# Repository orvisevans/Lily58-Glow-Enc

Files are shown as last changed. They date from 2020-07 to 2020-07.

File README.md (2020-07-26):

# Lily58 × qtkb Glow + Rotary Encoders

This is still very much under active development. I've ordered the pcb and parts and am waiting for them to arrive. Since then, I've found some incompatibilities between the design and product list. I've not yet tested in the real world or worked out there bugs.

Lily58 is 6×4+4keys column-staggered split keyboard.
This fork adds an encoder to the key below the controller.

I got this board manufactured by JLCPCB. Just upload the file called gerber.zip to their quote tool, choose how many (5 is minimum), choose your color, (default options are fine) and order! Mine were $8.40 for a set of 5 and $9.03 shipping in July 2020.

This picture is from the original Lily58 Glow. Pictures of this project are forthcoming.
Lily in the nighttime

## PCB Front

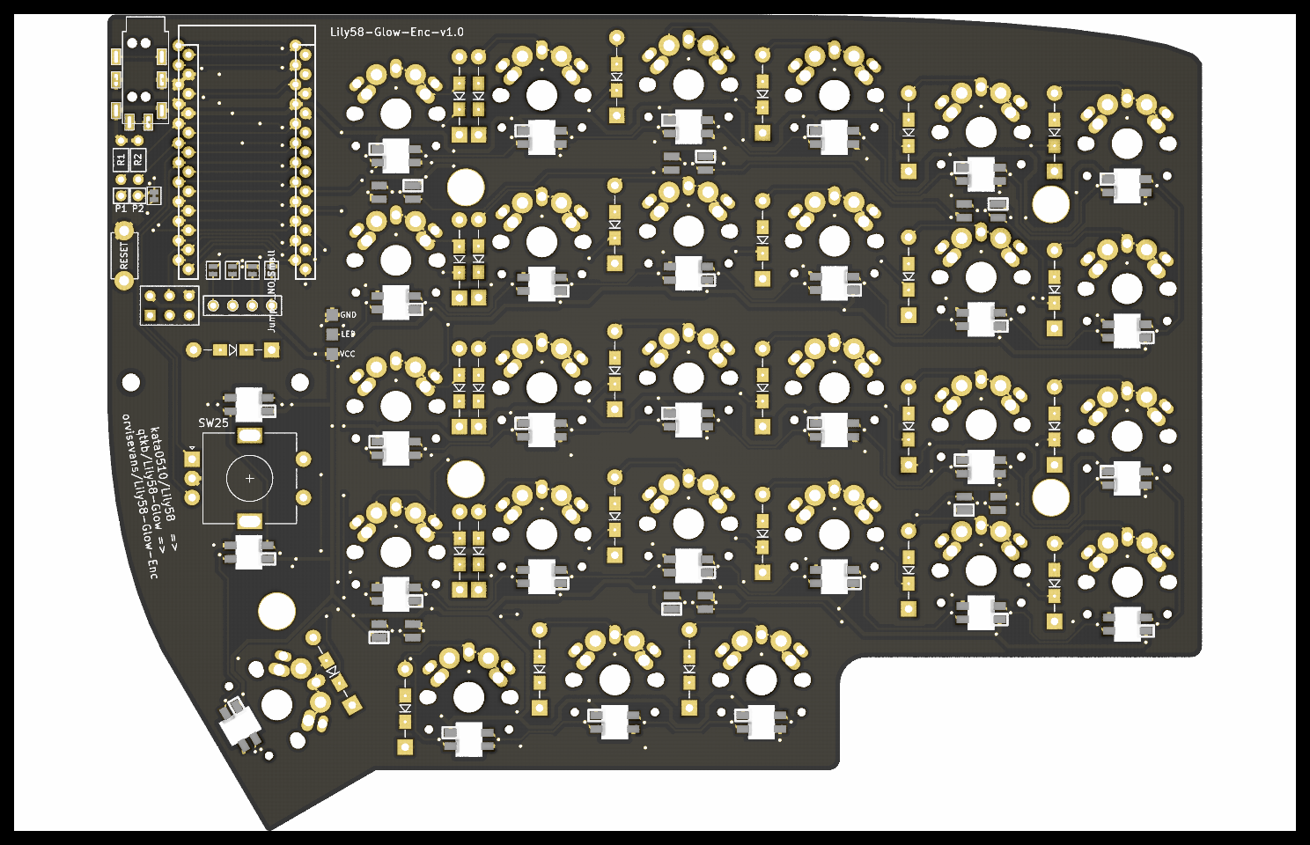
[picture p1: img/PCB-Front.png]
PCB Front


## PCB Back

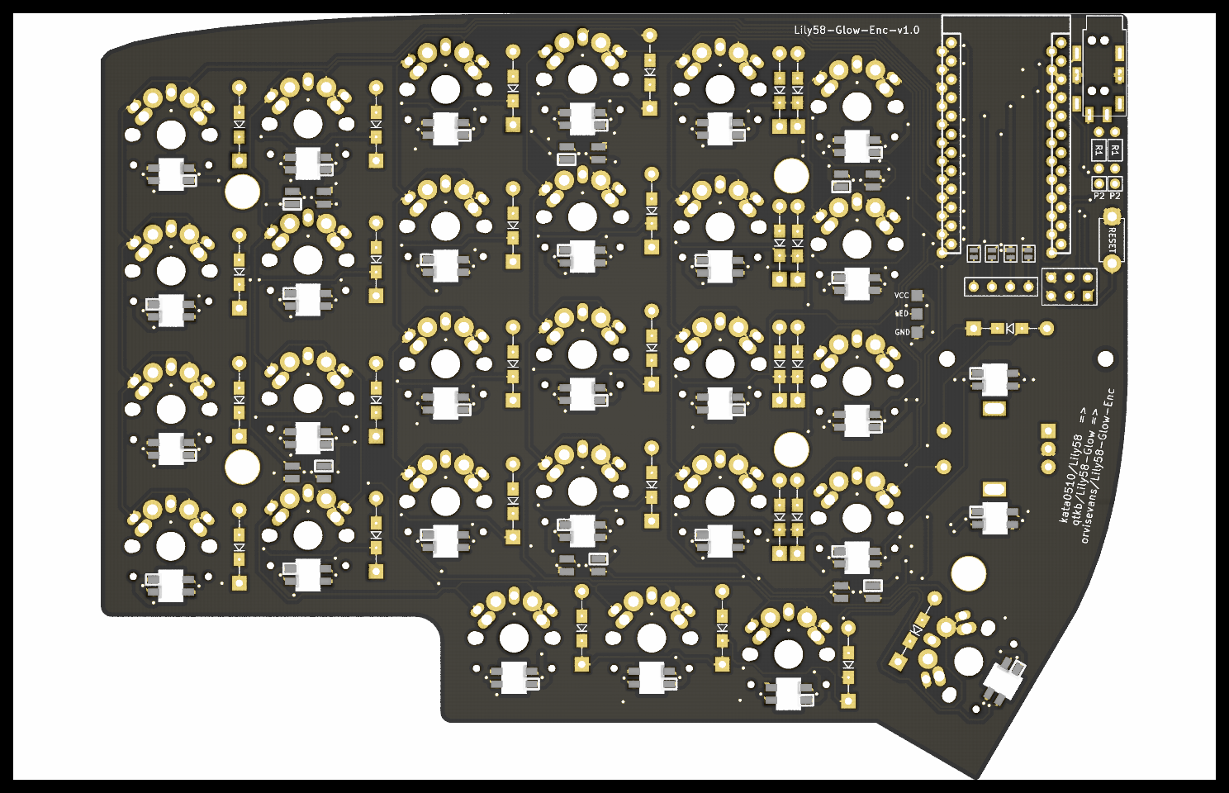
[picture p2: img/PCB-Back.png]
PCB Back


# Parts

| Part Name | Quantity | Link | Price/Unit | Total |
| --- | --- | --- | --- | --- |
| Lily58L PCB | 2 | JLCPCB | \$8.72 | \$17.43  |
| Lily58L Case | 1 | Using 2 more circuit boards as the bottom. No other case for now. | \$0.00 | \$0.00 |
| Pro Micro | 2 | https://www.aliexpress.com/item/32888212119.html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,searchweb201602_,searchweb201603_ | \$5.59 | \$11.17  |
| Micro USB Cable | 2 | -- | \$0.00 | \$0.00 |
| OLED module | 2 | https://www.aliexpress.com/item/32861875681.html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,searchweb201602_,searchweb201603_ | \$1.96 | \$3.92 |
| Rotary Encoder | 2 | https://www.aliexpress.com/item/32322425597.html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,searchweb201602_,searchweb201603_ | \$1.68 | \$3.35 |
| Knob | 2 | -- | | \$0.00 |
| Key switch (MX) | 58 | https://www.aliexpress.com/item/32973993662.html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,searchweb201602_,searchweb201603_ | \$0.29 | \$16.99  |
| Kailh switch socket | 58 | https://www.aliexpress.com/item/10000252734106.html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,searchweb201602_,searchweb201603_ | \$0.22 | \$12.90  |
| SK6812 Mini-E LEDs | 60 | https://www.aliexpress.com/item/4000475685852.html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,searchweb201602_,searchweb201603_ | \$0.18 | \$10.71  |
| SK6812 Mini LEDs | 12 | Use the above and snip the feet if necessary | | \$0.00 |
| Diodes 1N4148 (Through-hole) | 58 | https://www.aliexpress.com/item/1934432186.html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,searchweb201602_,searchweb201603_ | \$0.04 | \$2.48 |
| TRRS Jack | 2 | https://www.aliexpress.com/item/33029465106.html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,searchweb201602_,searchweb201603_ | \$1.63 | \$3.26 |
| TRRS Cable | 1 | https://www.aliexpress.com/item/33000197351.html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,searchweb201602_,searchweb201603_ | \$1.79 | \$1.79 |
| Tactile switch | 0 | Needed but not sourced. | | \$0.00 |
| Key Caps | 58 | https://www.aliexpress.com/item/32744591039.html?spm=a2g0o.cart.0.0.1fff3c00zqG7Sv&mp=1 | \$0.44 | \$25.5 |
| M2 Standoffs | 14 | https://www.aliexpress.com/item/32839434178.html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,searchweb201602_,searchweb201603_ | \$0.57 | \$7.99 |
| M2 Screws | 28 | https://www.aliexpress.com/item/32730208891.html?spm=2114.12010612.8148356.21.445e15ccXDyc9g | \$0.21 | \$5.74 |
| | | | Total: | \$115.80 |

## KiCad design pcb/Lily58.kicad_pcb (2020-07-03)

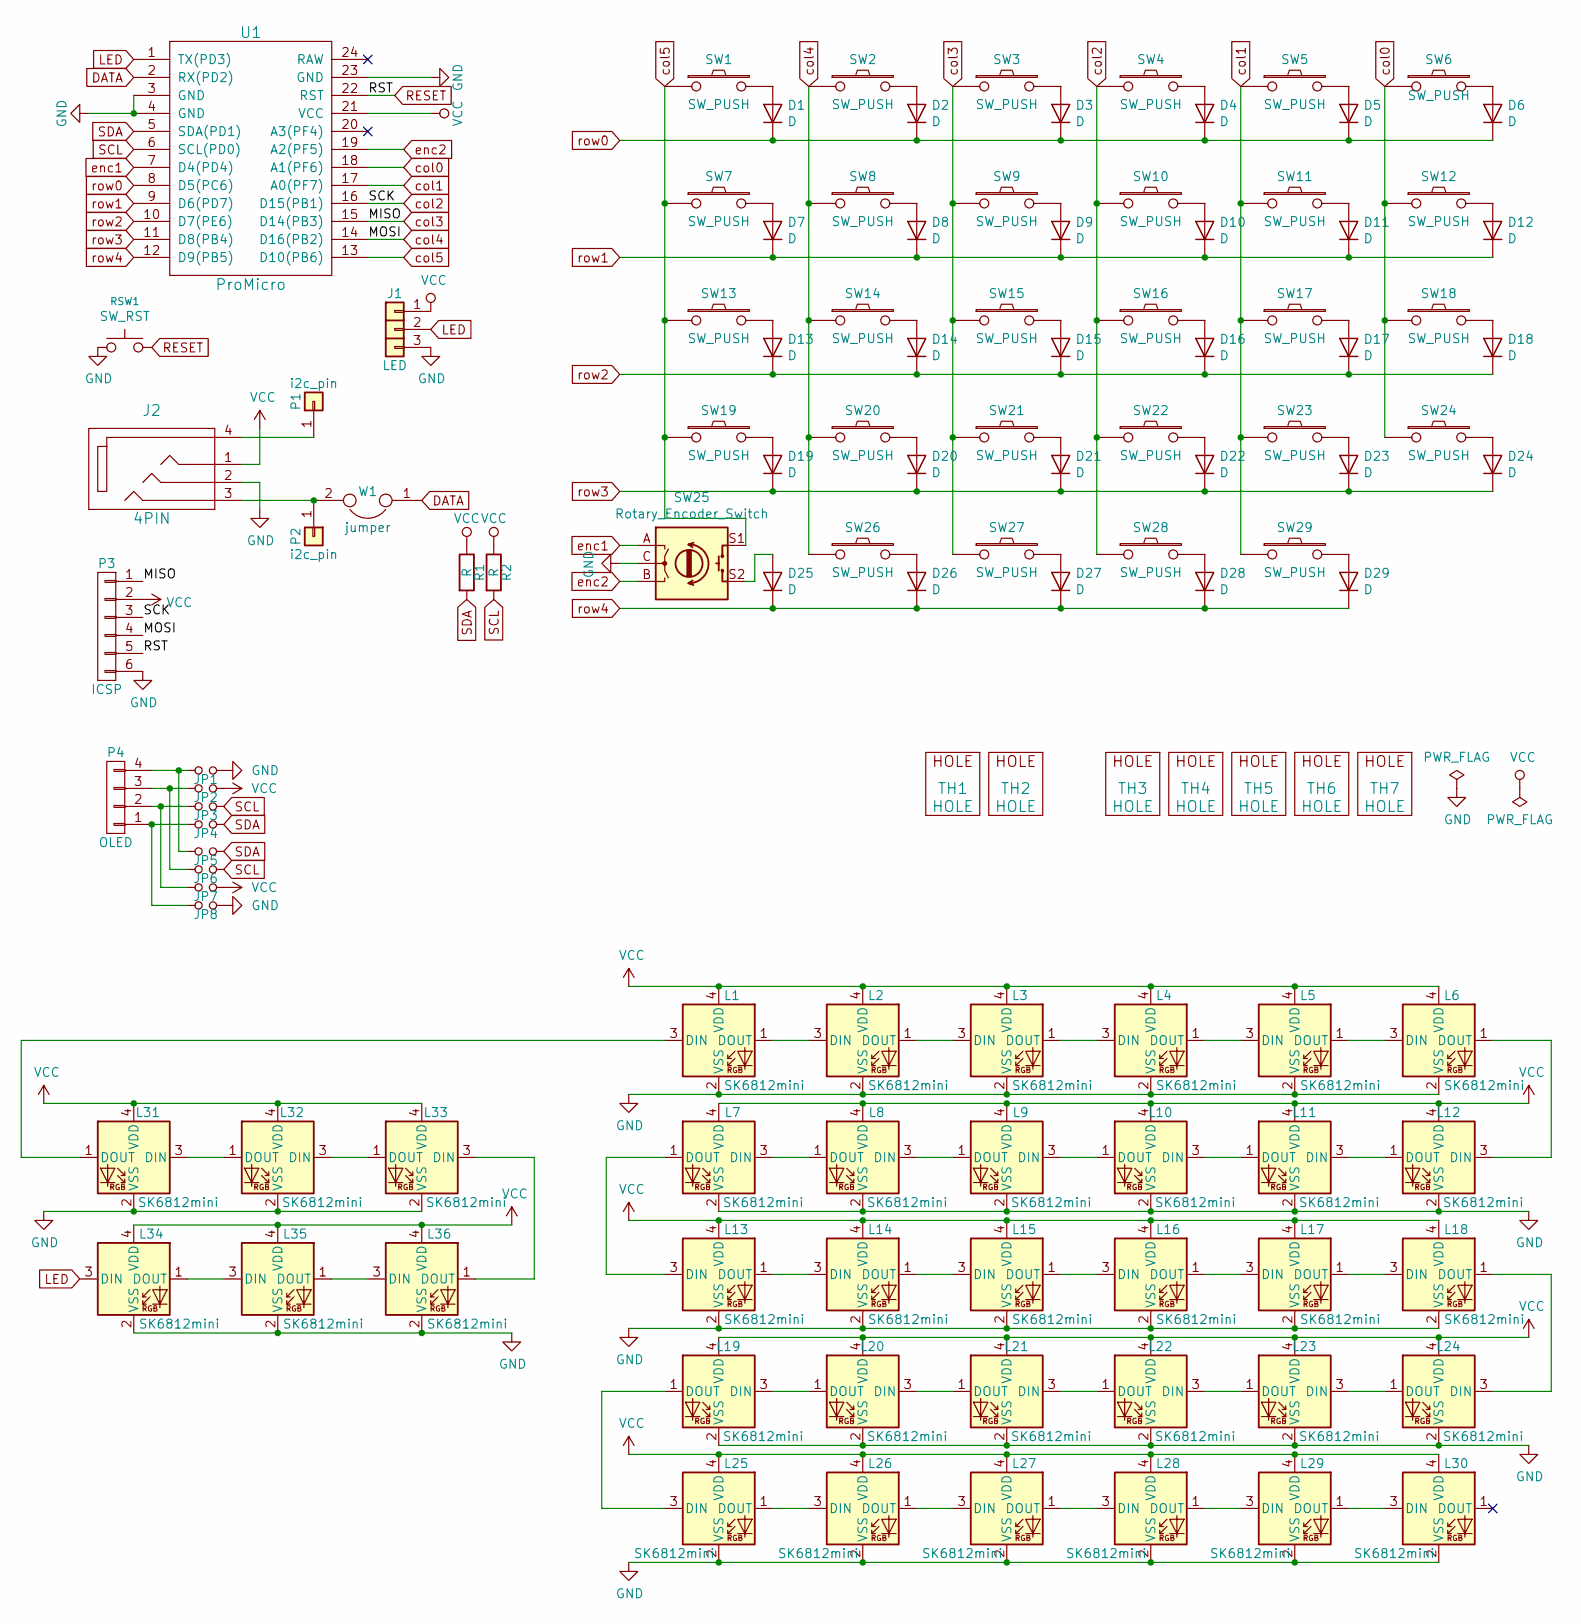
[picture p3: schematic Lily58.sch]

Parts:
D1, D2, D3, D4, D5, D6, D7, D8, D9, D10, D11, D12, D13, D14, D15, D16, D17, D18, D19, D20, D21, D22, D23, D24, D25, D26, D27, D28, D29: D; Diode_TH_SOD123
J1: LED; StripLED
J2: 4PIN; MJ-4PP-9
JP1, JP2, JP3, JP4, JP5, JP6, JP7, JP8: Jumper_NO_Small; Jumper
L1, L2, L3, L4, L5, L6, L7, L8, L9, L10, L11, L12, L13, L14, L15, L16, L17, L18, L19, L20, L21, L22, L23, L24, L25, L26, L27, L28, L29, L30: SK6812mini; SK6812MINI_rev
L31, L32, L33, L34, L35, L36: SK6812mini; SK6812MINI_underglow_rev
P1, P2: i2c_pin; 1pin_conn
P3: ICSP
P4: OLED; MY_SIL-4
R1, R2: R; RESISTOR_mini
RSW1: SW_RST; TACT_SWITCH_TVBP06
SW1, SW2, SW3, SW4, SW5, SW6, SW7, SW8, SW9, SW10, SW11, SW12, SW13, SW14, SW15, SW16, SW17, SW18, SW19, SW20, SW21, SW22, SW23, SW24, SW27, SW28, SW29: SW_PUSH; MX_PG1350_FLIP_HOLES_18mm
SW25: Rotary_Encoder_Switch; RotaryEncoder_Alps_EC11E-Switch_Vertical_H20mm
SW26: SW_PUSH; MX_PG1350_FLIP_HOLES_27mm
TH1, TH2: HOLE; HOLE_M2
TH3, TH4, TH5, TH6, TH7: HOLE; HOLE_M2_TH
U1: ProMicro; ProMicro_rev2
W1: jumper; jumper_data

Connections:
DATA: U1.2 (RX(PD2)), W1.1
GND: J1.3, J2.2, JP1.2, JP8.2, L1.2 (VSS), L2.2 (VSS), L3.2 (VSS), L4.2 (VSS), L5.2 (VSS), L6.2 (VSS), L7.2 (VSS), L8.2 (VSS), L9.2 (VSS), L10.2 (VSS), L11.2 (VSS), L12.2 (VSS), L13.2 (VSS), L14.2 (VSS), L15.2 (VSS), L16.2 (VSS), L17.2 (VSS), L18.2 (VSS), L19.2 (VSS), L20.2 (VSS), L21.2 (VSS), L22.2 (VSS), L23.2 (VSS), L24.2 (VSS), L25.2 (VSS), L26.2 (VSS), L27.2 (VSS), L28.2 (VSS), L29.2 (VSS), L30.2 (VSS), L31.2 (VSS), L32.2 (VSS), L33.2 (VSS), L34.2 (VSS), L35.2 (VSS), L36.2 (VSS), P3.6, RSW1.1, SW25.C, U1.3 (GND), U1.4 (GND), U1.23 (GND)
LED: J1.2, L34.3 (DIN), U1.1 (TX(PD3))
unnamed: D1.2 (A), SW1.2
unnamed: D2.2 (A), SW2.2
unnamed: D3.2 (A), SW3.2
unnamed: D4.2 (A), SW4.2
unnamed: D5.2 (A), SW5.2
unnamed: D6.2 (A), SW6.2
unnamed: D7.2 (A), SW7.2
unnamed: D8.2 (A), SW8.2
unnamed: D9.2 (A), SW9.2
unnamed: D10.2 (A), SW10.2
unnamed: D11.2 (A), SW11.2
unnamed: D12.2 (A), SW12.2
unnamed: D13.2 (A), SW13.2
unnamed: D14.2 (A), SW14.2
unnamed: D15.2 (A), SW15.2
unnamed: D16.2 (A), SW16.2
unnamed: D17.2 (A), SW17.2
unnamed: D18.2 (A), SW18.2
unnamed: D19.2 (A), SW19.2
unnamed: D20.2 (A), SW20.2
unnamed: D21.2 (A), SW21.2
unnamed: D22.2 (A), SW22.2
unnamed: D23.2 (A), SW23.2
unnamed: D24.2 (A), SW24.2
unnamed: D25.2 (A), SW25.S2
unnamed: D26.2 (A), SW26.2
unnamed: D27.2 (A), SW27.2
unnamed: D28.2 (A), SW28.2
unnamed: D29.2 (A), SW29.2
unnamed: J2.3, P2.1, W1.2
unnamed: J2.4, P1.1
unnamed: JP1.1, JP5.1, P4.4
unnamed: JP2.1, JP6.1, P4.3
unnamed: JP3.1, JP7.1, P4.2
unnamed: JP4.1, JP8.1, P4.1
unnamed: L1.1 (DOUT), L2.3 (DIN)
unnamed: L1.3 (DIN), L31.1 (DOUT)
unnamed: L2.1 (DOUT), L3.3 (DIN)
unnamed: L3.1 (DOUT), L4.3 (DIN)
unnamed: L4.1 (DOUT), L5.3 (DIN)
unnamed: L5.1 (DOUT), L6.3 (DIN)
unnamed: L7.3 (DIN), L8.1 (DOUT)
unnamed: L8.3 (DIN), L9.1 (DOUT)
unnamed: L9.3 (DIN), L10.1 (DOUT)
unnamed: L10.3 (DIN), L11.1 (DOUT)
unnamed: L11.3 (DIN), L12.1 (DOUT)
unnamed: L6.1 (DOUT), L12.3 (DIN)
unnamed: L13.1 (DOUT), L14.3 (DIN)
unnamed: L7.1 (DOUT), L13.3 (DIN)
unnamed: L14.1 (DOUT), L15.3 (DIN)
unnamed: L15.1 (DOUT), L16.3 (DIN)
unnamed: L16.1 (DOUT), L17.3 (DIN)
unnamed: L17.1 (DOUT), L18.3 (DIN)
unnamed: L18.1 (DOUT), L24.3 (DIN)
unnamed: L19.1 (DOUT), L25.3 (DIN)
unnamed: L19.3 (DIN), L20.1 (DOUT)
unnamed: L20.3 (DIN), L21.1 (DOUT)
unnamed: L21.3 (DIN), L22.1 (DOUT)
unnamed: L22.3 (DIN), L23.1 (DOUT)
unnamed: L23.3 (DIN), L24.1 (DOUT)
unnamed: L25.1 (DOUT), L26.3 (DIN)
unnamed: L26.1 (DOUT), L27.3 (DIN)
unnamed: L27.1 (DOUT), L28.3 (DIN)
unnamed: L28.1 (DOUT), L29.3 (DIN)
unnamed: L29.1 (DOUT), L30.3 (DIN)
unnamed: L31.3 (DIN), L32.1 (DOUT)
unnamed: L32.3 (DIN), L33.1 (DOUT)
unnamed: L33.3 (DIN), L36.1 (DOUT)
unnamed: L34.1 (DOUT), L35.3 (DIN)
unnamed: L35.1 (DOUT), L36.3 (DIN)
RESET: P3.5, RSW1.2, U1.22 (RST)
SCL: JP3.2, JP6.2, R2.2, U1.6 (SCL(PD0))
SDA: JP4.2, JP5.2, R1.2, U1.5 (SDA(PD1))
VCC: J1.1, J2.1, JP2.2, JP7.2, L1.4 (VDD), L2.4 (VDD), L3.4 (VDD), L4.4 (VDD), L5.4 (VDD), L6.4 (VDD), L7.4 (VDD), L8.4 (VDD), L9.4 (VDD), L10.4 (VDD), L11.4 (VDD), L12.4 (VDD), L13.4 (VDD), L14.4 (VDD), L15.4 (VDD), L16.4 (VDD), L17.4 (VDD), L18.4 (VDD), L19.4 (VDD), L20.4 (VDD), L21.4 (VDD), L22.4 (VDD), L23.4 (VDD), L24.4 (VDD), L25.4 (VDD), L26.4 (VDD), L27.4 (VDD), L28.4 (VDD), L29.4 (VDD), L30.4 (VDD), L31.4 (VDD), L32.4 (VDD), L33.4 (VDD), L34.4 (VDD), L35.4 (VDD), L36.4 (VDD), P3.2, R1.1, R2.1, U1.21 (VCC)
col0: SW6.1, SW12.1, SW18.1, SW24.1, U1.18 (A1(PF6))
col1: SW5.1, SW11.1, SW17.1, SW23.1, SW29.1, U1.17 (A0(PF7))
col2: P3.3, SW4.1, SW10.1, SW16.1, SW22.1, SW28.1, U1.16 (D15(PB1))
col3: P3.1, SW3.1, SW9.1, SW15.1, SW21.1, SW27.1, U1.15 (D14(PB3))
col4: P3.4, SW2.1, SW8.1, SW14.1, SW20.1, SW26.1, U1.14 (D16(PB2))
col5: SW1.1, SW7.1, SW13.1, SW19.1, SW25.S1, U1.13 (D10(PB6))
enc1: SW25.A, U1.7 (D4(PD4))
enc2: SW25.B, U1.19 (A2(PF5))
row0: D1.1 (K), D2.1 (K), D3.1 (K), D4.1 (K), D5.1 (K), D6.1 (K), U1.8 (D5(PC6))
row1: D7.1 (K), D8.1 (K), D9.1 (K), D10.1 (K), D11.1 (K), D12.1 (K), U1.9 (D6(PD7))
row2: D13.1 (K), D14.1 (K), D15.1 (K), D16.1 (K), D17.1 (K), D18.1 (K), U1.10 (D7(PE6))
row3: D19.1 (K), D20.1 (K), D21.1 (K), D22.1 (K), D23.1 (K), D24.1 (K), U1.11 (D8(PB4))
row4: D25.1 (K), D26.1 (K), D27.1 (K), D28.1 (K), D29.1 (K), U1.12 (D9(PB5))

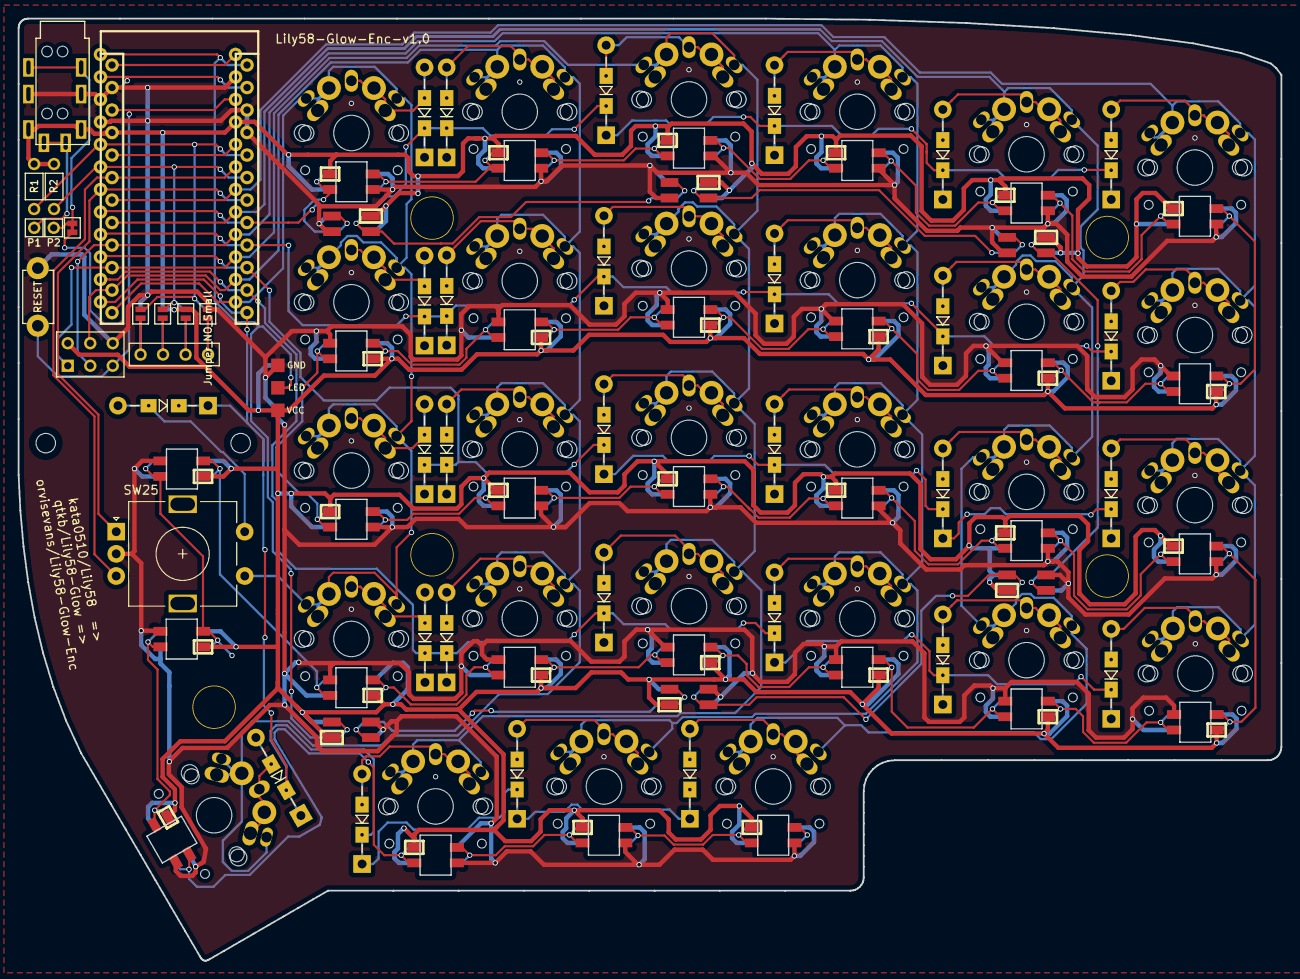
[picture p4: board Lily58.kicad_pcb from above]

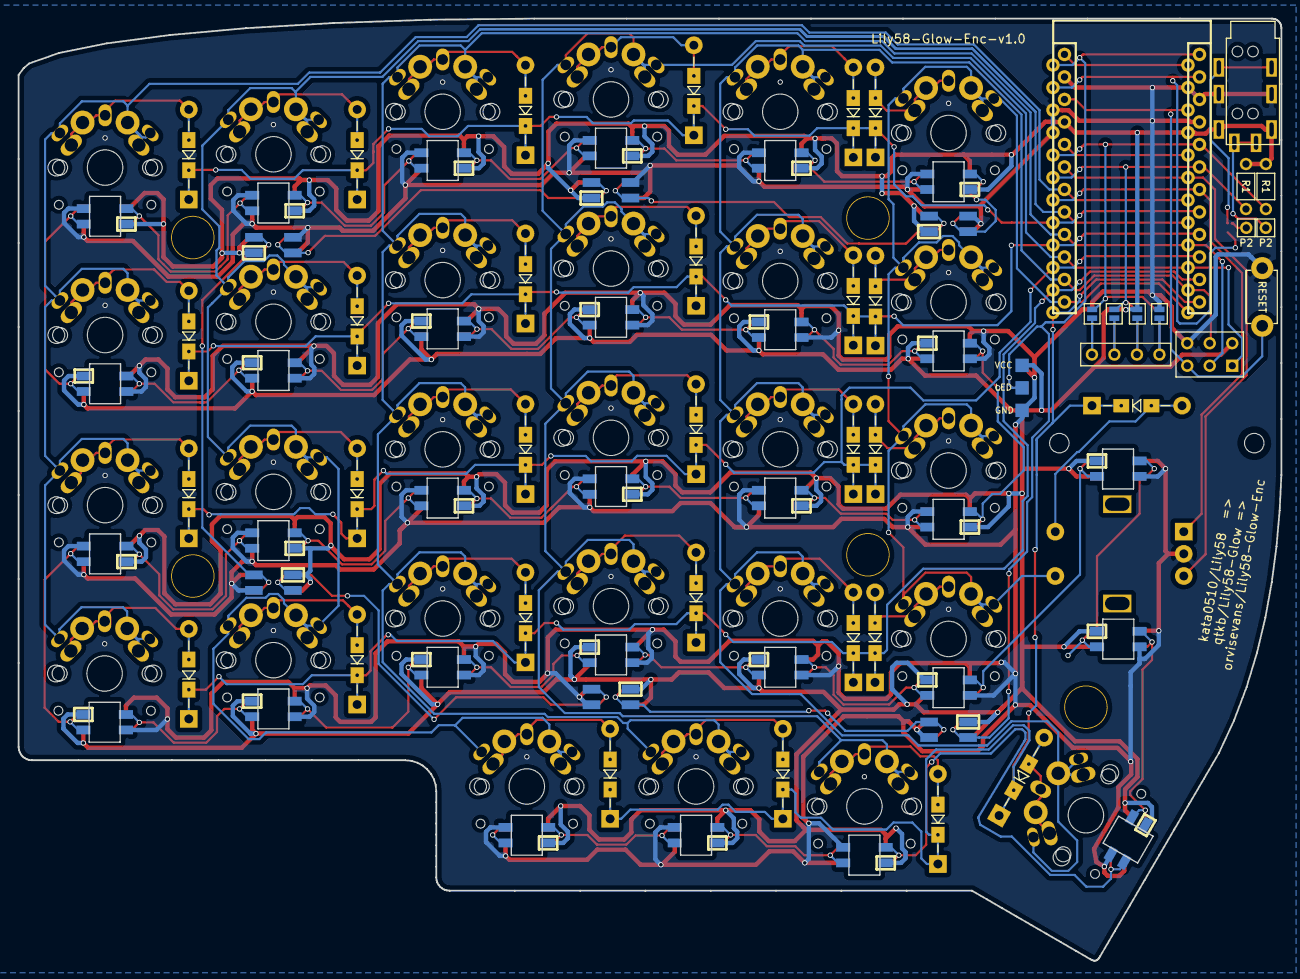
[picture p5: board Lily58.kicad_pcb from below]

Board: 2 copper layers, 142.5 x 106.3 mm, 120 parts (32 on the bottom side), 90 nets.

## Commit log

2020-07-03 Added Encoder and 1 led
    [Lily58.kicad_pcb, Lily58.sch]
2020-07-03 Updated README with new board
2020-07-03 Created gerbers
2020-07-03 One last board update
    [Lily58.kicad_pcb]
